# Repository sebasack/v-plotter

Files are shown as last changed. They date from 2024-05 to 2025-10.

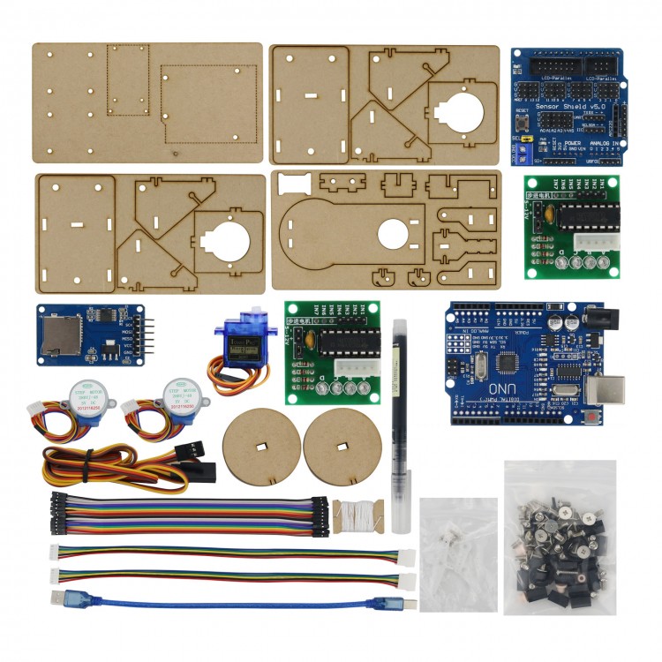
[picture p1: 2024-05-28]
hardware/mdf/1699426697-12-750x750.jpg

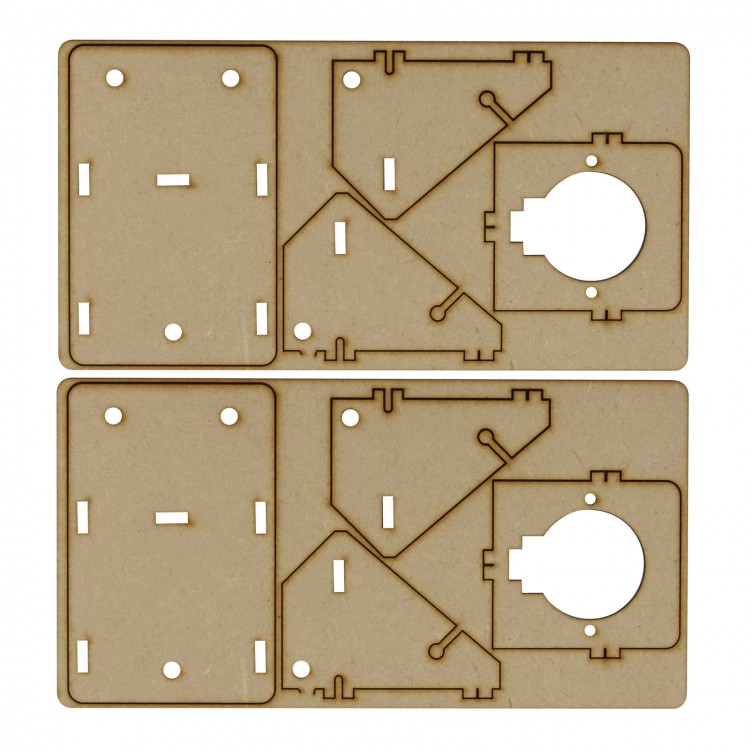
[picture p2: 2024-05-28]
hardware/mdf/1618448805-4-750x750.jpg

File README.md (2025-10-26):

# v-plotter

vertical plotter esp32 + wifi polargraph

      Como setear SSID y PASS de WIFI por primera vez:
      -----------------------------------------------

      1. Deshabilitar datos moviles del celular.
      2. Buscar la red llamada v-plotter y tratar de conecarse usando el pass '1234567890' .
      3. Entrar en la ip 192.168.4.1/config y configurar ssid y pass, presionar connect
      4. el AP v-plotter deberia desconectarse y deberia conectarse al wifi asignado.
      5. reiniciar el v-plotter
      6. en caso de falla recargar el firmware con la opcion 'Erase all flash before sketch upload' en Enabled, esto eliminara el ssid y pass guardados en la rom.

    Como plotear un svg:
    -------------------
       1. poner la gondola en posicion de dibujado (penDown)
       2. colocar la fibra en la gondola un milimetro por fuera de la estructura.
       3. poner la gondola en posicion de descanso (penLift)
       4. colocar el papel
       5. mover la gondola hasta su posicion de home, idealmente en el centro de la pizarra a 20 cms desde arriba.
       6. presionar el boton [input]->[set home]   para que la maquina sepa que ese es el punto de inicio.
       7. presionar [return to home] para asegurarse de que la gondola va as su home.
       8. borrar todo de la pantalla con [clear vector] y [clear image]
       9. presionar [load vector] y elegir la imagen, posicionarla en su lugar.
      10. presionar [move vector] para acomodarla y [resize vector] para acomodar su tamaÃ±o.
      11. presionar [select area] y elegir el area donde va a trabajar el plotter
      12. presionar [set frame to area]
      13. presionar [draw vector] para que genere el gcode
      14. presionar nuevamente [return to home] para que la gondola vuelva en su sitio inicial.
      15. activar la cola

    como convertir imagen a lineas y plotear:
    ----------------------------------------
       1. poner la gondola en posicion de dibujado (penDown)
       2. colocar la fibra en la gondola un milimetro por fuera de la estructura.
       3. poner la gondola en posicion de descanso (penLift)
       4. colocar el papel
       5. mover la gondola hasta su posicion de home, idealmente en el centro de la pizarra a 20 cms desde arriba.
       6. presionar el boton [input]->[set home]   para que la maquina sepa que ese es el punto de inicio.
       7. presionar [return to home] para asegurarse de que la gondola va as su home.
       8. borrar todo de la pantalla con [clear vector] y [clear image]
       9. presionar [load image from file] y elegir el archivo grafico
      10. poner en posicion con [move image]
      11. escalar con [resize image]
      12. presionar [select area] y elegir el area donde va a trabajar el plotter
      13. presionar [set frame to area]
      14. ir a [trace]
      15. presionar [capture]
      16. presionar [draw capture] para que genere el gcode
      17. ir a [input] para que muestre el path que seguira el plotter
      18. presionar nuevamente [return to home] para que la gondola vuelva en su sitio inicial.
      19. activar la cola

    Creaci�n de una imagen clasica (foto, dibujo, etc.)
    ---------------------------------------------------

       1. poner la gondola en posicion de dibujado (penDown)
       2. colocar la fibra en la gondola un milimetro por fuera de la estructura.
       3. poner la gondola en posicion de descanso (penLift)
       4. colocar el papel
       5. mover la gondola hasta su posicion de home, idealmente en el centro de la pizarra a 20 cms desde arriba.
       6. presionar el boton [input]->[set home]   para que la maquina sepa que ese es el punto de inicio.
       7. presionar [return to home] para asegurarse de que la gondola va as su home.
       8. borrar todo de la pantalla con [clear vector] y [clear image]
       9. presionar [load image from file] y elegir el archivo grafico
      10. poner en posicion con [move image]
      11. escalar con [resize image]
      12. presionar [select area] y elegir el area donde va a trabajar el plotter
      13. presionar [set frame to area]
      14. presionar [slect frame] para confirmar el �rea a dibujar.
      15. presionar [render pixels]

            Aparece una tabla con las diferentes opciones disponibles en cuanto a patrones, inicio y otras opciones:

            Deber�s elegir desde que punto comenzara el dibujo:
                  parte superior derecha
                  abajo a la derecha
                  abajo a la izquierda
                  arriba a la izquierda

            Hay 6 matrices de renderizado disponibles y deber�s elegir una para dibujar:
                  onda cuadrada de frecuencia variable
                  onda cuadrada de tama�o variable
                  onda cuadrada salida
                  garabatear
                  espirales
                  Diente de sierra

      16. presionar el bot�n [generate commands] para generar los comandos gcode.
      17. presionar nuevamente [return to home] para que la gondola vuelva en su sitio inicial.
      18. activar la cola

    Plotear archivo gcode guardado en SD:
    ------------------------------------
       1. poner la gondola en posicion de dibujado (penDown)
       2. colocar la fibra en la gondola un milimetro por fuera de la estructura.
       3. poner la gondola en posicion de descanso (penLift)
       4. colocar el papel
       5. mover la gondola hasta su posicion de home, idealmente en el centro de la pizarra a 20 cms desde arriba.
       6. presionar el boton [input]->[set home]   para que la maquina sepa que ese es el punto de inicio.
       7. presionar [return to home] para asegurarse de que la gondola va as su home.
       8. Crear el archivo gcode y guardarlo en el root de la SD con el nombre 'AUTORUN.TXT'
       9. reiniciar el sistema.

    Aclaraciones:
    ------------
      * aumentar el [setup]->[step multiplier]  le da mas resolucion a la impresion.
      * si se baja la resolucion parece escrito a mano.
      * Para imprimir texto pequeÃ±o primero pasarlo a hershey text usando inkscape, ir a 'Extensions' > 'Text' > 'Hershey Text'
        (fuente: https://support.shapertools.com/hc/en-us/articles/360055222354-Create-a-single-line-text-with-Inkscape)

    Instalar vpype para convertir imagenes a svg:
    --------------------------------------------

      * instalar con
            pipx install "vpype[all]"

      * instalar plugins
            pipx inject vpype vpype-vectrace
            pipx inject vpype deduplicate
            pipx inject vpype vpype-pixelart
            pipx inject vpype 'git+https://github.com/serycjon/vpype-flow-imager.git#egg=vpype-flow-imager[all]'
            pipx install vpype-ttf --include-deps
            pipx inject vpype vpype-occult
            pipx inject vpype hatched
            pipx inject vpype vpype-perspective
            pipx inject vpype vpype-gcode

      * desinstalarlo con
            pipx uninstall vpype

      * para entrar en la version dockerizada de vpype:
            docker exec -it vpype bash

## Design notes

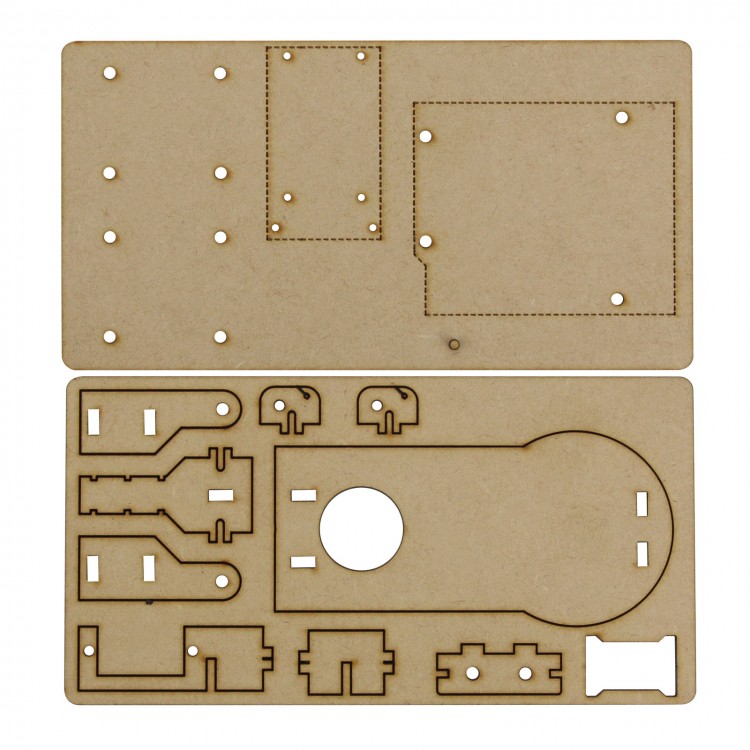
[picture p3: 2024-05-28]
hardware/mdf/1618448807-5-750x750.jpg

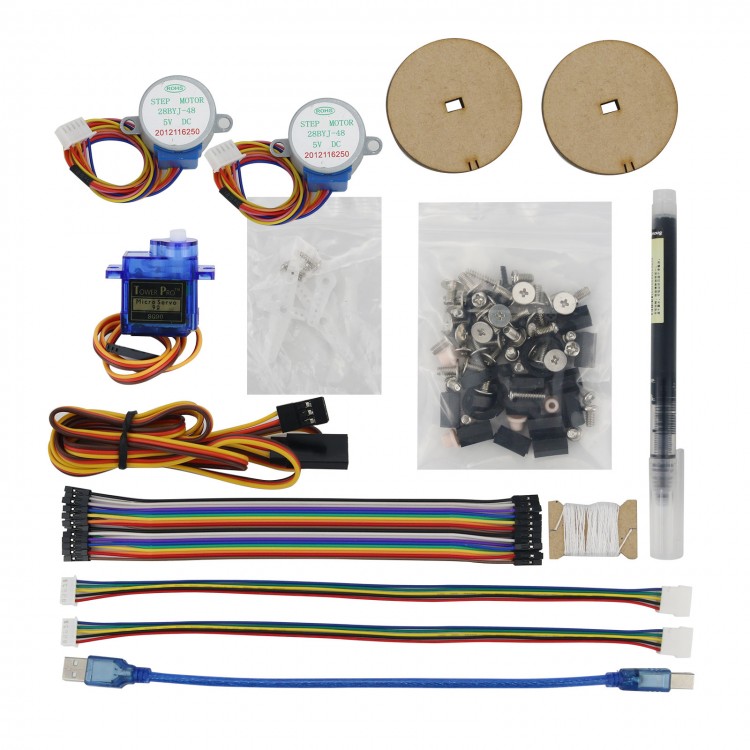
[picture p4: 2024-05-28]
hardware/mdf/1618448812-9-750x750.jpg

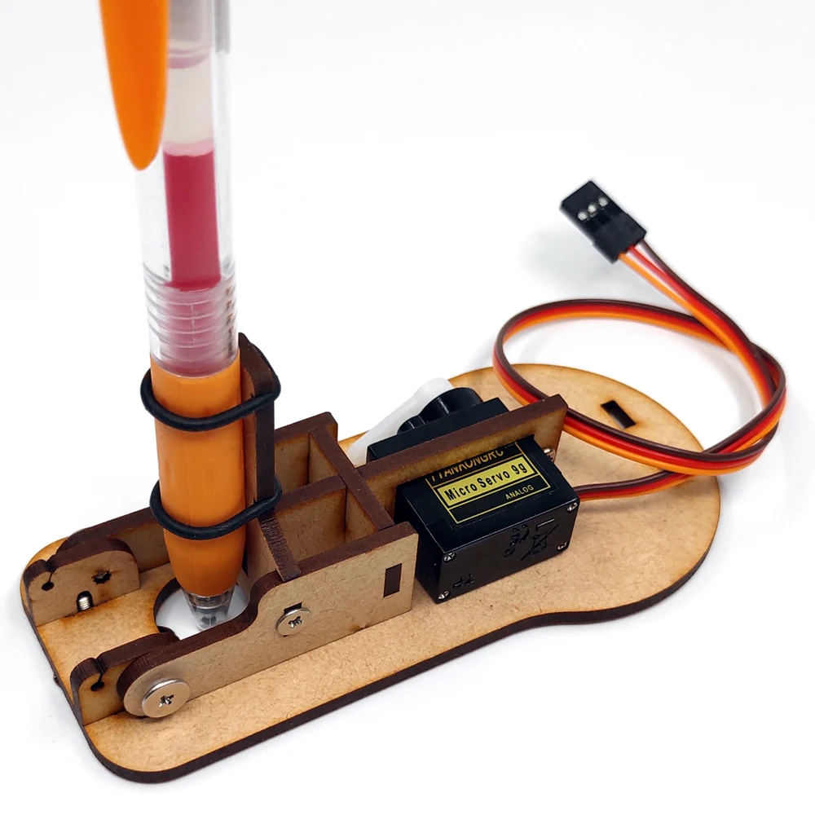
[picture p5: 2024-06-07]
hardware/mdf/H9e8e9794f45f4d0299c1774f670f7c20u.webp

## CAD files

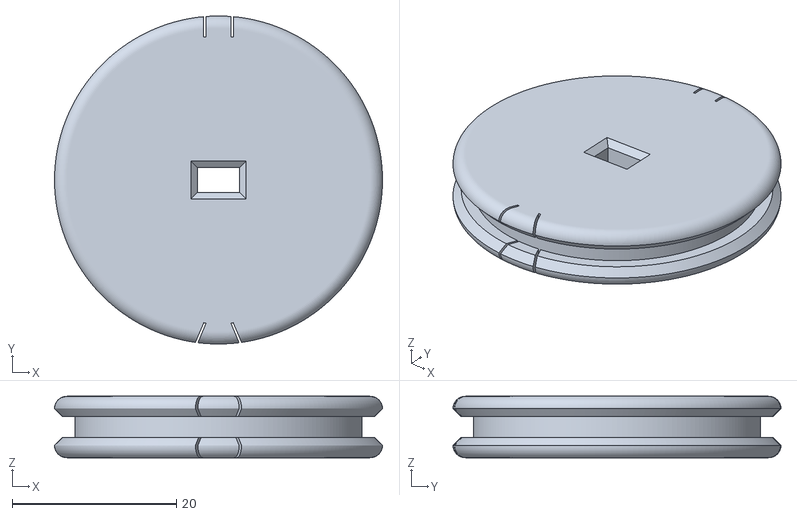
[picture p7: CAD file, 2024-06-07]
hardware/3d_printer/Spool.stl
40.0 x 40.0 x 7.50

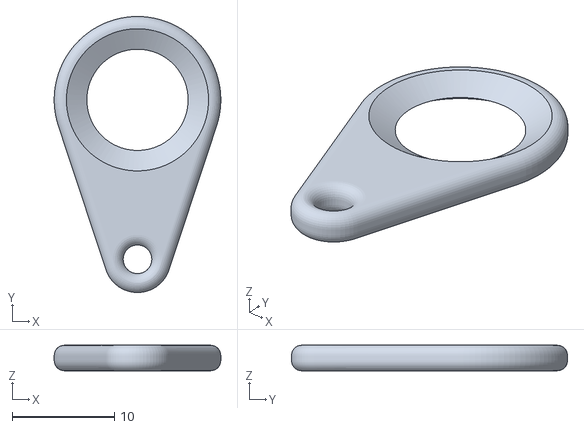
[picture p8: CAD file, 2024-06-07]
hardware/3d_printer/TwineRing.stl
16.3 x 27.0 x 2.50

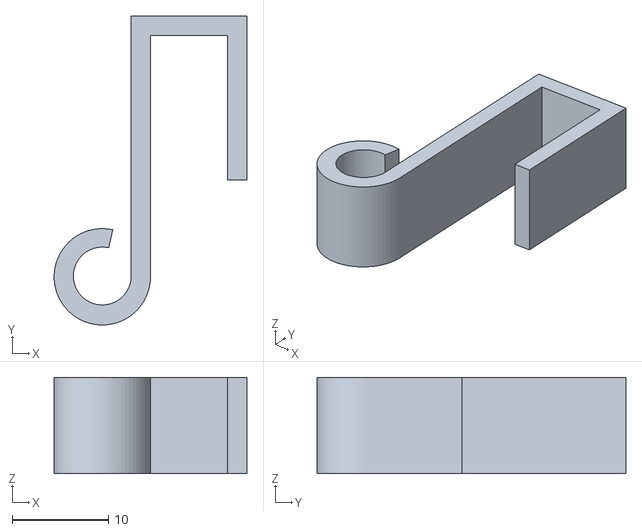
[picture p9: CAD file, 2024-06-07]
hardware/3d_printer/WireClamp.stl
20.0 x 32.1 x 10.0

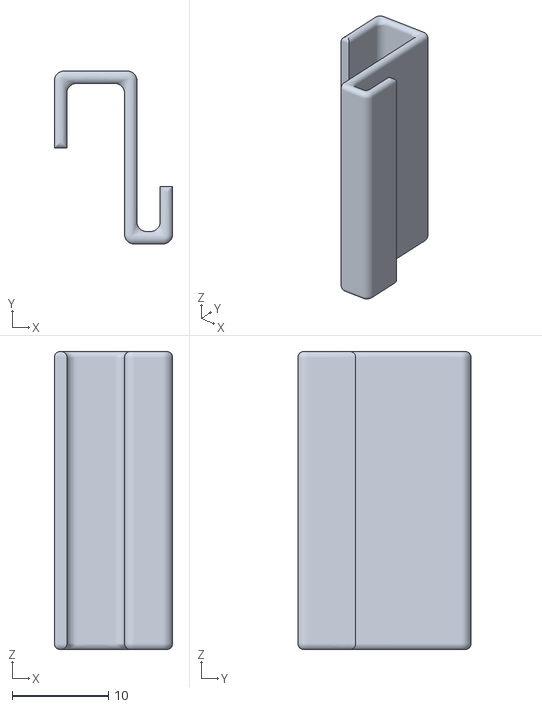
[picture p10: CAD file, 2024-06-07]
hardware/3d_printer/Hook.stl
12.3 x 18.0 x 31.0

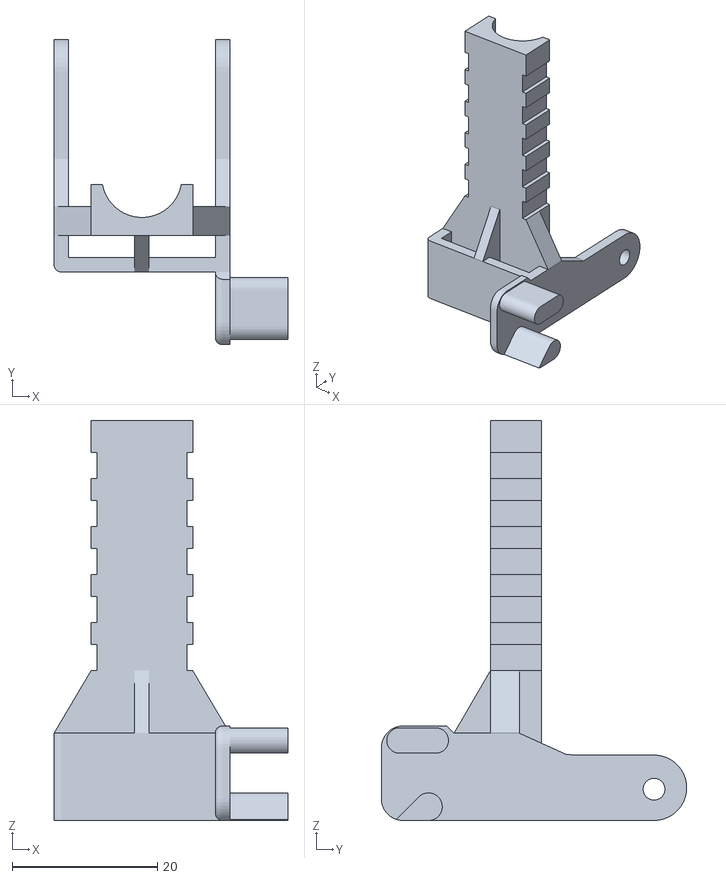
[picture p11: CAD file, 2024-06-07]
hardware/3d_printer/Lever.stl
32.2 x 42.0 x 55.0

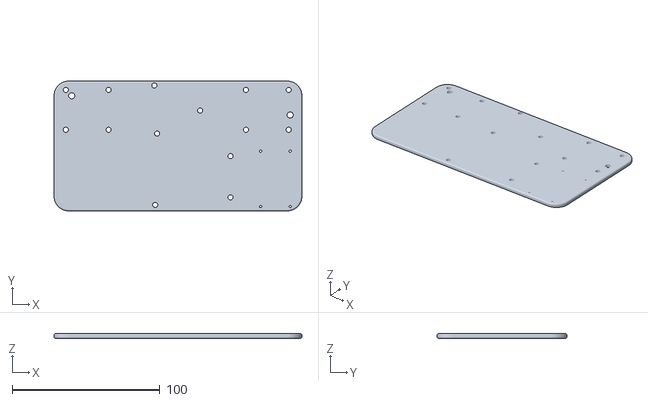
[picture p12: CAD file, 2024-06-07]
hardware/3d_printer/BasePlate Uno.stl
168.0 x 88.0 x 3.20

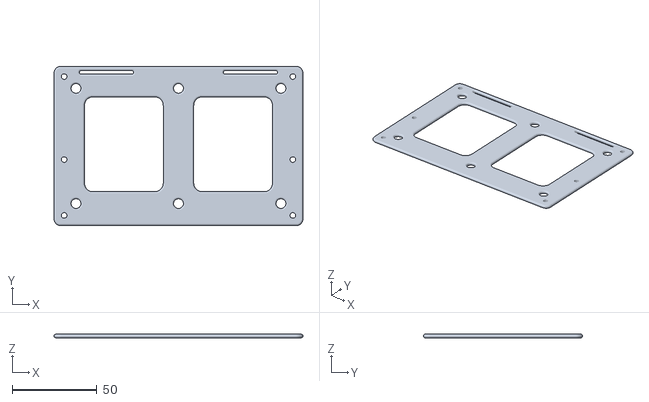
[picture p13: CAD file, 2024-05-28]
hardware/3d_printer/BasePlate PCB.stl
147.0 x 94.0 x 2.20

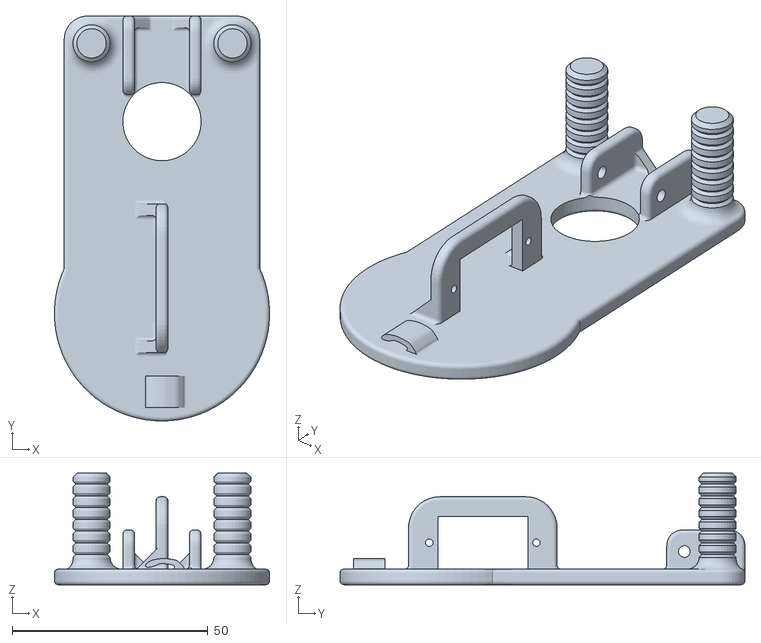
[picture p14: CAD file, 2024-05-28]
hardware/3d_printer/Sledge.stl
55.0 x 103.5 x 28.5

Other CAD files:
hardware/3d_printer/BasePlate.f3d
hardware/3d_printer/Sledge.f3d
hardware/3d_printer/Spool.f3d
hardware/3d_printer/StepperStand.f3d
hardware/3d_printer/WireClamp.f3d

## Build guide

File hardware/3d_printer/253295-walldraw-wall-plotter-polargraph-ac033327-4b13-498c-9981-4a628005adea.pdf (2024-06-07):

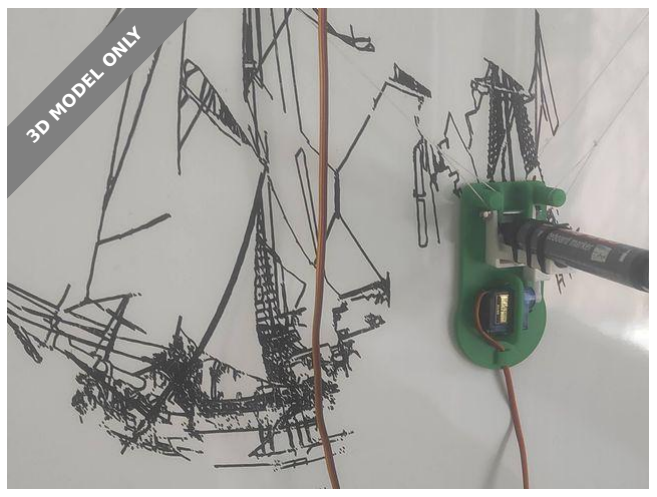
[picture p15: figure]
3D MODEL ONLY

## Summary

The Walldrawer project is a funny maker project for everyone.

Gadgets (https://www.printables.com/model?categoryId=21) > Other Gadgets (https://www.printables.com/model?categoryId=43)

Tags: arduino | esp32 | robotics | battery | electronics
fusion360 | office | pcb | programming | robotic
steppermotor | uln2003 | uno

The Walldrawer project is a usual maker project which is suitable for old and young.
There is so much fun in watching it working on giant sheets, walls or whiteboards.

I modified usual constructions, now everybody can build one on a 3D printer with an Arduino UNO
or, for the more engaged Makers, a selfmade PCB with ESP32.

My solution is below 30 bucks, beside some parts you may find around.

I published the full project in German language on GitHub: https://github.com/Pontifex42/Walldraw

Pontifex Maximus (https://www.printables.com/social/299558/about)

## Walldraw / Wall

## plotter / Polargraph

VIEW IN BROWSER (https://www.printables.com/model/253295-walldraw-wall-plotter-polargraph)

updated 6. 8. 2022 | published 6. 8. 2022

## Model files

There you find all files, code, instructions, part list photos, videos and all you need.
If requested, I'll translate everything to english.

spool.f3d

stepperstand.f3d

sledge.f3d

baseplate.f3d

wireclamp.f3d

sledge.stl

lever.stl

spool.stl

twinering.stl

## Other files

## License

This work is licensed under a
Creative Commons (4.0 International License)

Attribution-ShareAlike (http://creativecommons.org/licenses/by-sa/4.0/)

✖ | Sharing without ATTRIBUTION
✔ | Remix Culture allowed

stepperstand.stl

baseplate-pcb.stl

baseplate-uno.stl

wireclamp.stl

hook.stl

wandplotter.pdf

✔ | Commercial Use
✔ | Free Cultural Works
✔ | Meets Open Definition

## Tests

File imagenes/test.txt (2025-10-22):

C14,END
C01,15665,15665,END
C14,END
C17,16957,15583,2,END
C13,END
C17,20543,19423,2,END
C14,END
C17,19768,18039,2,END
C13,END
C17,19849,18105,2,END
C17,20055,18163,2,END
C17,20275,18114,2,END
C17,20374,18051,2,END
C17,20456,17968,2,END
C17,20555,17760,2,END
C17,20548,17541,2,END
C17,20505,17444,2,END
C17,20350,17306,2,END
C17,20248,17275,2,END
C17,20138,17272,2,END
C17,19921,17350,2,END
C17,19751,17520,2,END
C17,19674,17738,2,END
C17,19709,17950,2,END
C17,19766,18036,2,END
C14,END
C17,19827,16183,2,END
C13,END
C17,16515,19451,2,END
C14,END
C17,17670,18484,2,END
C13,END
C17,17657,18380,2,END
C17,17699,18270,2,END
C17,17785,18181,2,END
C17,17894,18133,2,END
C17,18000,18141,2,END
C17,18076,18200,2,END
C17,18105,18297,2,END
C17,18081,18408,2,END
C17,18008,18506,2,END
C17,17904,18567,2,END
C17,17794,18578,2,END
C17,17705,18534,2,END
C14,END
C17,18794,20058,2,END
C13,END
C17,19155,19246,2,END
C17,18624,19381,2,END
C17,18758,20137,2,END
C14,END
C17,18791,16124,2,END
C13,END
C17,17686,15547,2,END
C14,END
C17,16646,16331,2,END
C13,END
C17,17755,16525,2,END
C17,18905,15452,2,END
C17,18392,16780,2,END
C17,18445,16837,2,END
C17,19457,17258,2,END
C17,18002,17707,2,END
C17,17532,19158,2,END
C17,17076,18089,2,END
C17,15735,18598,2,END
C17,16825,17455,2,END
C17,16646,16337,2,END
C14,END
C17,16025,17493,2,END
C13,END
C17,16213,17300,2,END
C17,16335,17415,2,END
C17,16149,17607,2,END
C17,16086,17550,2,END
C14,END
C17,15927,17584,2,END
C13,END
C17,16115,17754,2,END
C17,16484,17383,2,END
C17,16248,17150,2,END
C17,15872,17534,2,END
C14,END
C17,15767,17620,2,END
C13,END
C17,16081,17902,2,END
C17,16633,17353,2,END
C17,16285,17000,2,END
C17,15719,17576,2,END
C14,END
C17,15612,17664,2,END
C13,END
C17,16055,18057,2,END
C17,16789,17317,2,END
C17,16322,16846,2,END
C17,15563,17620,2,END
C14,END
C17,14722,17955,2,END
C13,END
C17,18689,21329,2,END
C17,18769,21332,2,END
C17,21747,18410,2,END
C17,21766,18332,2,END
C17,18467,14260,2,END
C17,18418,14201,2,END
C17,14671,17913,2,END
C14,END
C17,14417,18036,2,END
C13,END
C17,18707,21619,2,END
C17,18789,21651,2,END
C17,22061,18441,2,END
C17,22098,18365,2,END
C17,18545,13886,2,END
C17,14380,18006,2,END
C14,END
C01,15665,15665,END

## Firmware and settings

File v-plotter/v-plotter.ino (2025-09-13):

/**
*  Polargraph Server for ESP32 based microcontroller boards.
*  Written by Sandy Noble
*  Released under GNU License version 3.
*  http://www.polargraph.co.uk
*  https://github.com/euphy/polargraph_server_polarshield_esp32
*  https://github.com/euphy/polargraph/wiki
*  https://github.com/obstruse/PGNH/tree/main



This version is for the Polarshield 3, which aggregates:

  * ESP32 DOIT-DEVKIT V1 
  * 2x UNL2003 stepper drivers   
  * SD card reader     

**/

char fileName[] = __FILE__;
char temp[1000];



#include "wifiTask.h"
#include "httpTask.h"
#include "httpWifiTask.h"
// #include "commsTask.h"

#include <SD.h>
#include "FS.h"
#include "SPIFFS.h"
#include <SPI.h>
// #include <TFT_eSPI.h> // Hardware-specific library

#include <AccelStepper.h>
#include <MultiStepper.h>
#include <ESP32Servo.h>

#include <Preferences.h>



/*
Avoid global variables whenever possible...
*/

/* Definition of a function that can be attached to a Button Specification
and will get executed when the button is pushed..
*/
// typedef int (*button_Action) (int buttonId);


// 2D coordinates struct
typedef struct
{
  long x;
  long y;
} Coord2D;

typedef struct
{
  Coord2D pos;
  Coord2D size;
} Rectangle;


/*  ===========================================================
         CONFIGURATION!!
    =========================================================== */

/*  ===========================================================
         Define what kind of driver breakout you're using.
         (By commenting out the one's you _haven't_ got.)
    =========================================================== */
#ifndef MOTHERBOARD
// #define MOTHERBOARD NODEMCU32S
// #define MOTHERBOARD POLARSHIELD
// #define MOTHERBOARD RAMPS14
// #define MOTHERBOARD TFTSHIELD

#define MOTHERBOARD ESP32_UNL2003

#endif

// #define POLARSHIELD 1
// #define RAMPS14 2
// #define TFTSHIELD 3
// #define NODEMCU32S 4
#define ESP32_UNL2003 5

/*  ===========================================================
    Control whether to look for touch input or update LCD
    Comment this out if you DON'T have an LCD connected
=========================================================== */
// #define USE_LCD

/*  ===========================================================
    Some debugging flags
=========================================================== */

// #define DEBUG_COMMS
// #define DEBUG_COMMS_BUFF
//  #define DEBUG_PENLIFT
//  #define DEBUG_STEPRATE

boolean debugComms = false;

// Set REPEAT_CAL to true instead of false to run calibration
// again, otherwise it will only be done once.
// Repeat calibration if you change the screen rotation.
#define REPEAT_CAL false

/*  ===========================================================
    These variables are common to all polargraph server builds
=========================================================== */

const String FIRMWARE_VERSION_NO = "2.3.0";


#if MOTHERBOARD == RAMPS14
const String MB_NAME = "RAMPS14";
#elif MOTHERBOARD == NODEMCU32S
const String MB_NAME = "NODEMCU32S";
#elif MOTHERBOARD == POLARSHIELD
const String MB_NAME = "POLARSHIELD";
#elif MOTHERBOARD == TFTSHIELD
const String MB_NAME = "TFTSHIELD";
#elif MOTHERBOARD == ESP32_UNL2003
const String MB_NAME = "ESP32_UNL2003";
#endif

/*  ===========================================================
    Preferences is the way to store non-volatile values in ESP32.
=========================================================== */

Preferences preferences;

// Pen raising servo , CAMBIAR DESDE POLARGRAPH!!
Servo penHeight;
const int DEFAULT_DOWN_POSITION =90;//90
const int DEFAULT_UP_POSITION = 123;//180
static int upPosition = DEFAULT_UP_POSITION;
static int downPosition = DEFAULT_DOWN_POSITION;
static int penLiftSpeed = 3; // ms between steps of moving motor
#if MOTHERBOARD == RAMPS14
#define PEN_HEIGHT_SERVO_PIN 4
#elif MOTHERBOARD == POLARSHIELD
#define PEN_HEIGHT_SERVO_PIN 9
#elif MOTHERBOARD == NODEMCU32S
#define PEN_HEIGHT_SERVO_PIN 22
#elif MOTHERBOARD == ESP32_UNL2003
#define PEN_HEIGHT_SERVO_PIN 15
#endif
boolean isPenUp = false;

// working machine specification
const long DEFAULT_MACHINE_WIDTH = 882;
const long DEFAULT_MACHINE_HEIGHT = 1100;
const float DEFAULT_MM_PER_REV = 125.66;
const int DEFAULT_STEPS_PER_REV = 4076;
const int DEFAULT_STEP_MULTIPLIER = 8; // mas chico tiene menos resolucion

static int motorStepsPerRev = DEFAULT_STEPS_PER_REV;
static float mmPerRev = DEFAULT_MM_PER_REV;
static int stepMultiplier = DEFAULT_STEP_MULTIPLIER;

static Coord2D machineSizeMm = {DEFAULT_MACHINE_WIDTH, DEFAULT_MACHINE_HEIGHT};

 // float startLength = ((float) startLengthMM / (float) mmPerRev) * (float) motorStepsPerRev;
 //                   =         481   /   125.66          * 4076
 //                   =                   15704.828
static long startLengthStepsA = 125312;// 15664 * 8
static long startLengthStepsB = 125312;// 15664 * 8

const float DEFAULT_MAX_SPEED = 1000.0;
const float DEFAULT_ACCELERATION = 400.0;
float currentMaxSpeed = DEFAULT_MAX_SPEED;
static float currentAcceleration = DEFAULT_ACCELERATION;
volatile static boolean usingAcceleration = true;

float mmPerStep = mmPerRev / (stepMultiplier * motorStepsPerRev);
float stepsPerMm = (stepMultiplier * motorStepsPerRev) / mmPerRev;

static Coord2D machineSizeSteps = {(long)((float)machineSizeMm.x * stepsPerMm), (long)((float)machineSizeMm.y *stepsPerMm)};
static long maxLength = 0;

const float DEFAULT_PEN_WIDTH = 0.5f;//0.f8
static float penWidth = DEFAULT_PEN_WIDTH; // line width in mm

/*==========================================================================
    COMMUNICATION PROTOCOL, how to chat
  ========================================================================*/

// max length of incoming command
const int INLENGTH = 90;
const char INTERMINATOR = 10;
const char SEMICOLON = 59;

// static char currentCommand[INLENGTH+1];
char currentCommand[INLENGTH + 1];
char currentCommandRaw[INLENGTH + 1];

static char inCmd[10];
static char inParam1[20];
static char inParam2[20];
static char inParam3[20];
static char inParam4[20];
static byte inNoOfParams = 0;
boolean paramsExtracted = false;
// boolean usingCrc = false;

boolean reportingPosition = true;
// boolean requestResend = false;
// boolean checkingForReceivedCommand = false;

#define OUT_CMD_SYNC_STR "SYNC,"

char MSG_ERROR_STR[] = "MSG,E,";
char MSG_INFO_STR[] = "MSG,I,";
char MSG_DEBUG_STR[] = "MSG,D,";
char MSG_COMPLETE_STR[] = "MSG,C:";

// period between status rebroadcasts
// unsigned long comms_rebroadcastStatusInterval =4000;// estaba en 4000
// Chrono broadcastStatusChrono;

/*==========================================================================
    MOTOR interfaces
  ========================================================================*/

extern AccelStepper motorA;
extern AccelStepper motorB;

volatile boolean currentlyRunning = true;
volatile boolean backgroundRunning = false;

volatile long lastOperationTime = 0L;
static long motorIdleTimeBeforePowerDown = 30000L; // 30000=30 seg
static boolean automaticPowerDown = true;
volatile long lastInteractionTime = 0L;

// Pixel drawing
static boolean pixelDebug = true;
static boolean lastWaveWasTop = true;

//  Drawing direction
const static byte DIR_NE = 1;
const static byte DIR_SE = 2;
const static byte DIR_SW = 3;
const static byte DIR_NW = 4;

const static byte DIR_N = 5;
const static byte DIR_E = 6;
const static byte DIR_S = 7;
const static byte DIR_W = 8;

static int globalDrawDirection = DIR_NW;

const static byte DIR_MODE_AUTO = 1;
const static byte DIR_MODE_PRESET = 2;
const static byte DIR_MODE_RANDOM = 3;
static int globalDrawDirectionMode = DIR_MODE_AUTO;

static const byte ALONG_A_AXIS = 0;
static const byte ALONG_B_AXIS = 1;
static const byte SQUARE_SHAPE = 0;
static const byte SAW_SHAPE = 1;

// Command names
const static char COMMA[] = ",";
const static char CMD_END[] = ",END";
const static String CMD_CHANGELENGTH = "C01";
const static String CMD_SETPENWIDTH = "C02";
const static String CMD_DRAWPIXEL = "C05";
const static String CMD_DRAWSCRIBBLEPIXEL = "C06";
const static String CMD_CHANGEDRAWINGDIRECTION = "C08";
const static String CMD_SETPOSITION = "C09";
const static String CMD_TESTPATTERN = "C10";
const static String CMD_TESTPENWIDTHSQUARE = "C11";
const static String CMD_PENDOWN = "C13";
const static String CMD_PENUP = "C14";
const static String CMD_CHANGELENGTHDIRECT = "C17";
const static String CMD_SETMACHINESIZE = "C24";
const static String CMD_SETMACHINENAME = "C25";
const static String CMD_GETMACHINEDETAILS = "C26";
const static String CMD_RESETEEPROM = "C27";
const static String CMD_SETMACHINEMMPERREV = "C29";
const static String CMD_SETMACHINESTEPSPERREV = "C30";
const static String CMD_SETMOTORSPEED = "C31";
const static String CMD_SETMOTORACCEL = "C32";
const static String CMD_SETMACHINESTEPMULTIPLIER = "C37";
const static String CMD_SETPENLIFTRANGE = "C45";
const static String CMD_PIXELDIAGNOSTIC = "C46";
const static String CMD_SET_DEBUGCOMMS = "C47";

// Instrumentation about running background motor tasks
volatile DRAM_ATTR long runCounter = 0L;
volatile DRAM_ATTR long lastPeriodStartTime = 0L;
volatile DRAM_ATTR long sampleBuffer[3] = {0L, 0L, 0L};
volatile DRAM_ATTR int sampleBufferSlot = 0;
volatile DRAM_ATTR long totalTriggers = 0L;
volatile DRAM_ATTR long totalSamplePeriods = 0L;
volatile DRAM_ATTR long steppedCounter = 0L;
volatile DRAM_ATTR long steppedBuffer[3] = {0L, 0L, 0L};
volatile DRAM_ATTR boolean aStepped = false;
volatile DRAM_ATTR boolean bStepped = false;

SemaphoreHandle_t xMutex;

// Ticker commsRunner;

/*===========================================================
    These variables are for the polarshield
=========================================================== */

const static String CMD_TESTPENWIDTHSCRIBBLE = "C12";
const static String CMD_DRAWSAWPIXEL = "C15,";
const static String CMD_DRAWCIRCLEPIXEL = "C16";
const static String CMD_SET_ROVE_AREA = "C21";
const static String CMD_DRAWDIRECTIONTEST = "C28";
const static String CMD_MODE_STORE_COMMANDS = "C33";
const static String CMD_MODE_EXEC_FROM_STORE = "C34";
const static String CMD_MODE_LIVE = "C35";
const static String CMD_RANDOM_DRAW = "C36";
const static String CMD_START_TEXT = "C38";
const static String CMD_DRAW_SPRITE = "C39";
const static String CMD_CHANGELENGTH_RELATIVE = "C40";
const static String CMD_SWIRLING = "C41";
const static String CMD_DRAW_RANDOM_SPRITE = "C42";
const static String CMD_DRAW_NORWEGIAN = "C43";
const static String CMD_DRAW_NORWEGIAN_OUTLINE = "C44";
const static String CMD_AUTO_CALIBRATE = "C48";

/*  End stop pin definitions  */
// there are no endstop switches, so this and the calibrate can be removed
const int ENDSTOP_MOTORA_PIN = 34;
const int ENDSTOP_MOTORB_PIN = 35;

long limitStepsMotorA = 0;
long limitStepsMotorB = 0;


// size and location of rove area
Rectangle roveAreaMm = {200, 120, 210, 297};
Rectangle roveAreaSteps = {
    (long)((float)roveAreaMm.pos.x * stepsPerMm), (long)((float)roveAreaMm.pos.y *stepsPerMm),
    (long)((float)roveAreaMm.size.x *stepsPerMm), (long)((float)roveAreaMm.size.y *stepsPerMm)};

boolean swirling = false;
String spritePrefix = "";
int textRowSize = 200;
int textCharSize = 180;

boolean useRoveArea = false;

int commandNo = 0;
int errorInjection = 0;

boolean storeCommands = false;
boolean drawFromStore = false;
String commandFilename = "";

// sd card stuff
const int sdChipSelectPin = 05;
//boolean sdCardInit = false;

// set up variables using the SD utility library functions:
File root;
boolean cardPresent = false;
boolean cardInit = false;
boolean echoingStoredCommands = false;

// the file itself
File pbmFile;

// information we extract about the bitmap file
long pbmWidth, pbmHeight;
float pbmScaling = 1.0;
int pbmDepth, pbmImageoffset;
long pbmFileLength = 0;
float pbmAspectRatio = 1.0;

volatile int speedChangeIncrement = 100;
volatile int accelChangeIncrement = 100;
volatile float penWidthIncrement = 0.05;
volatile int moveIncrement = 400;

// buttons_actions.ino, impl_ps.ino, sd.ino
boolean currentlyDrawingFromFile = false;
String currentlyDrawingFilename = "";

// calibrate.ino, impl_ps.ino
boolean powerIsOn = false;
boolean isCalibrated = false;
boolean canCalibrate = false;

// Colour scheme
// As seen on http://www.barth-dev.de/online/rgb565-color-picker/
// uint16_t getAsRgb565(uint8_t red, uint8_t green, uint8_t blue){
//  return (((red & 0b11111000)<<8) + ((green & 0b11111100)<<3)+(blue>>3));
//}

/*-----------------------------------------------------------------*/
/*-----------------------------------------------------------------*/
void setup(){
  Serial.begin(115200); // set up Serial library at 57600 bps
  Serial.println(F("\nPOLARGRAPH ON!"));
  Serial.print(F("v"));
  Serial.println(FIRMWARE_VERSION_NO);
  Serial.print(F("Hardware: "));
  Serial.println(MB_NAME);



  Serial.print(F("Servo pin: "));
  Serial.println(PEN_HEIGHT_SERVO_PIN);

  /*-----------------------------------------------------------------*/
  configuration_motorSetup();

  // Load configuration
  preferences.begin("polargraphsd", false);
  eeprom_loadMachineSpecFromEeprom();
  configuration_setup();

  /*-----------------------------------------------------------------*/
  Serial.println("create task: wifi");
  wifiTaskCreate();

  Serial.println("create task: http");
  httpTaskCreate();
  httpWifiTaskCreate();

  /*-----------------------------------------------------------------*/
  Serial.println("create task: commsRead"); // read command
  commsReadTaskCreate();

  Serial.println("create task: commsCommand"); // execute command
  commsCommandTaskCreate();

  Serial.println("create task: releaseMotors"); // chequea si tiene que desenergizar motores
  implReleaseMotorsCreate();

//  Serial.println("create task: externalControl"); // tarea que maneja el control externo de los motores
  //externalControlCreate();


//  Serial.println("create task: remoteDebug"); // actualiza debug
//  Serial.remoteDebugCreate();

  //*-----------------------------------------------------------------*/
  // set the pen lift, raise it to begin.
  pinMode(PEN_HEIGHT_SERVO_PIN, OUTPUT);
  delay(200);
  penlift_penUp();

  /* set endstop motors pins */
  pinMode(ENDSTOP_MOTORA_PIN, INPUT_PULLUP);
  pinMode(ENDSTOP_MOTORB_PIN, INPUT_PULLUP);

  sd_autorunSD();
}

/*-----------------------------------------------------------------*/
/*-----------------------------------------------------------------*/
void loop(){
  // vTaskDelete(NULL);
  vTaskDelay(portMAX_DELAY);

  
}

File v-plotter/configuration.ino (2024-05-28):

/**
*  Polargraph Server for ESP32 based microcontroller boards.
*  Written by Sandy Noble
*  Released under GNU License version 3.
*  http://www.polargraph.co.uk
*  https://github.com/euphy/polargraph_server_polarshield_esp32

Configuration.

This is one of the core files for the polargraph server program.
It sets up the motor objects (AccelSteppers), and has default
values for the motor, sprocket and microstepping combinations used
by polargraphs so far.

*/

// =================================================================
// Polarshield motor driver board
// This uses stepstick-format stepper drivers on arduino pins 3 to 8.



#if MOTHERBOARD == POLARSHIELD
  #define MOTOR_A_ENABLE_PIN 3
  #define MOTOR_A_STEP_PIN 4
  #define MOTOR_A_DIR_PIN 5

  #define MOTOR_B_ENABLE_PIN 6
  #define MOTOR_B_STEP_PIN 7
  #define MOTOR_B_DIR_PIN 8

  #define MOTOR_C_ENABLE_PIN 30
  #define MOTOR_C_STEP_PIN 31  
  #define MOTOR_C_DIR_PIN 32
  AccelStepper motorA(1, MOTOR_A_STEP_PIN, MOTOR_A_DIR_PIN);
  AccelStepper motorB(1, MOTOR_B_STEP_PIN, MOTOR_B_DIR_PIN);

#elif MOTHERBOARD == RAMPS14

  // Uses E1 driver on RAMPS
  #define MOTOR_A_ENABLE_PIN 30
  #define MOTOR_A_STEP_PIN 36
  #define MOTOR_A_DIR_PIN 34

  // Uses Y motor driver on RAMPS
  #define MOTOR_B_ENABLE_PIN 56
  #define MOTOR_B_STEP_PIN 60
  #define MOTOR_B_DIR_PIN 61
  AccelStepper motorA(1, MOTOR_A_STEP_PIN, MOTOR_A_DIR_PIN);
  AccelStepper motorB(1, MOTOR_B_STEP_PIN, MOTOR_B_DIR_PIN);

#elif MOTHERBOARD == TFTSHIELD

  // Uses E1 driver on RAMPS
  #define MOTOR_A_ENABLE_PIN 21
  #define MOTOR_A_STEP_PIN 20
  #define MOTOR_A_DIR_PIN 19

  // Uses Y motor driver on RAMPS
  #define MOTOR_B_ENABLE_PIN 18
  #define MOTOR_B_STEP_PIN 17
  #define MOTOR_B_DIR_PIN 16
  AccelStepper motorA(1, MOTOR_A_STEP_PIN, MOTOR_A_DIR_PIN);
  AccelStepper motorB(1, MOTOR_B_STEP_PIN, MOTOR_B_DIR_PIN);

#elif MOTHERBOARD == NODEMCU32S

  #define MOTOR_A_ENABLE_PIN 27
  #define MOTOR_A_STEP_PIN 14
  #define MOTOR_A_DIR_PIN 12

  #define MOTOR_B_ENABLE_PIN 13
  #define MOTOR_B_STEP_PIN 4
  #define MOTOR_B_DIR_PIN 15
  AccelStepper motorA(1, MOTOR_A_STEP_PIN, MOTOR_A_DIR_PIN);
  AccelStepper motorB(1, MOTOR_B_STEP_PIN, MOTOR_B_DIR_PIN);

#elif MOTHERBOARD == ESP32_UNL2003
    // Contributed by @j0nson
    // Initialize ULN2003 stepper driver
    // first number is type of stepper motor, 4 for a normal 4 wire step motor, 8 for a halfstepped normal 4 wire motor
    //Connection Directions
    // MotorA
    //ULN2003  Arduino  AcceStepper Init
    //IN1      2        2
    //IN2      3        4
    //IN3      4        3
    //IN4      5        5
    // MotorB
    //ULN2003  Arduino  AcceStepper Init
    //IN1      6        6
    //IN2      7        8
    //IN3      8        7
    //IN4      9        9
    
    //for a 28YBJ-48 Stepper, change these parameters above
    //Step angle (8-step) 5.625deg, 64 steps per rev
    //Step angle (4-step) 11.25deg, 32 steps per rev
    //gear reduction ratio 1/63.68395
    
    // motorStepsPerRev = 32 * 63.68395 = 2038; //for 4 step sequence
    // motorStepsPerRev = 64 * 63.68395 = 4076; //for 8 step sequence
    
    //motorStepsPerRev = 4076;
    //mmPerRev = 63;
    
    //DEFAULT_STEPS_PER_REV = 4076;
    //DEFAULT_MM_PER_REV = 63;
    
       
  // AccelStepper motorA(8, 26,33,32,25);  //   
  // AccelStepper motorB(8, 13,14,27,12);  //   

// esta configuracion dibuja invertido de cabeza
 //   AccelStepper motorA(8, 25,32,33,26);  //inv
  //  AccelStepper motorB(8, 13,14,27,12);  
       
    AccelStepper motorA(8, 26,33,32,25);
    AccelStepper motorB(8, 12,27,14,13);  //inv
       
  //  AccelStepper motorA(8, 25,32,33,26);  //inv
  //  AccelStepper motorB(8, 12,27,14,13);  //inv

//INVIERTO A Y B

  //  AccelStepper motorB(8, 26,33,32,25);
  //  AccelStepper motorA(8, 13,14,27,12);  
       
  //  AccelStepper motorB(8, 25,32,33,26);  //inv
  //  AccelStepper motorA(8, 13,14,27,12);  
       
  //  AccelStepper motorB(8, 26,33,32,25);
  //  AccelStepper motorA(8, 12,27,14,13);  //inv
       
  //  AccelStepper motorB(8, 25,32,33,26);  //inv
  //  AccelStepper motorA(8, 12,27,14,13);  //inv

   



#endif




void configuration_motorSetup(){

#ifdef DEBUG
  Serial.print(F("A: En:"));
  Serial.print(MOTOR_A_ENABLE_PIN);
  Serial.print(F(", St:"));
  Serial.print(MOTOR_A_STEP_PIN);
  Serial.print(F(", Di:"));
  Serial.println(MOTOR_A_DIR_PIN);

  Serial.print(F("B: En:"));
  Serial.print(MOTOR_B_ENABLE_PIN);
  Serial.print(F(", St:"));
  Serial.print(MOTOR_B_STEP_PIN);
  Serial.print(F(", Di:"));
  Serial.println(MOTOR_B_DIR_PIN);
#endif
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

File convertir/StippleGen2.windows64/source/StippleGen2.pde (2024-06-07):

/**
 
 StippleGen_2_31
 
 SVG Stipple Generator, v. 2.31
 Copyright (C) 2013 by Windell H. Oskay, www.evilmadscientist.com
 
 Full Documentation: http://wiki.evilmadscience.com/StippleGen
 Blog post about the release: http://www.evilmadscientist.com/go/stipple2
 
 
 An implementation of Weighted Voronoi Stippling:
 http://mrl.nyu.edu/~ajsecord/stipples.html
 
 *******************************************************************************
 
 Change Log:
 
 
 v 2.3
 * Forked from 2.1.1
 * Fixed saving bug
 
 v 2.20
 * [Cancelled development branch.]
 
 v 2.1.1
 * Faster now, with number of stipples calculated at a time.
 
 v 2.1.0
 * Now compiling in Processing 2.0b6
 * selectInput() and selectOutput() calls modified for Processing 2.
 
 v 2.02
 * Force files to end in .svg
 * Fix bug that gave wrong size to stipple files saved white stipples on black background
 
 v 2.01:  
 * Improved handling of Save process, to prevent accidental "not saving" by users.
 
 v 2.0:  
 * Add tone reversal option (white on black / black on white)
 * Reduce vertical extent of GUI, to reduce likelihood of cropping on small screens
 * Speling corections 
 * Fixed a bug that caused unintended cropping of long, wide images
 * Reorganized GUI controls
 * Fail less disgracefully when a bad image type is selected.
 
 *******************************************************************************
 
 
 
 Program is based on the Toxic Libs Library ( http://toxiclibs.org/ )
 & example code:
 http://forum.processing.org/topic/toxiclib-voronoi-example-sketch
 
 
 Additional inspiration:
 Stipple Cam from Jim Bumgardner
 http://joyofprocessing.com/blog/2011/11/stipple-cam/
 
 and 
 
 MeshLibDemo.pde - Demo of Lee Byron's Mesh library, by 
 Marius Watz - http://workshop.evolutionzone.com/
 
 
 Requires ControlP5 library and Toxic Libs library:
 http://www.sojamo.de/libraries/controlP5/
 http://hg.postspectacular.com/toxiclibs/downloads
 
 
 */


/*  
 * 
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
 * http://creativecommons.org/licenses/LGPL/2.1/
 * 
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
 * You should have received a copy of the GNU Lesser General Public
 * License along with this library; if not, write to the Free Software
 * Foundation, Inc., 51 Franklin St, Fifth Floor, Boston, MA  02110-1301  USA
 */


// You need the controlP5 library from http://www.sojamo.de/libraries/controlP5/
import controlP5.*;    

//You need the Toxic Libs library: http://hg.postspectacular.com/toxiclibs/downloads

import toxi.geom.*;
import toxi.geom.mesh2d.*;
import toxi.util.datatypes.*;
import toxi.processing.*;

// helper class for rendering
ToxiclibsSupport gfx;

import javax.swing.UIManager; 
import javax.swing.JFileChooser; 




// Feel free to play with these three default settings:
int maxParticles = 2000;   // Max value is normally 10000.  Press 'x' key to allow 50000 stipples. (SLOW)
float MinDotSize = 1.75; //2;
float DotSizeFactor = 4;  //5;
float cutoff =  0;  // White cutoff value


int cellBuffer = 100;  //Scale each cell to fit in a cellBuffer-sized square window for computing the centroid.


// Display window and GUI area sizes:
int mainwidth; 
int mainheight;
int borderWidth;
int ctrlheight;
int TextColumnStart;



float lowBorderX;
float hiBorderX;
float lowBorderY;
float hiBorderY;



float MaxDotSize;
boolean ReInitiallizeArray; 
boolean pausemode;
boolean fileLoaded;
int SaveNow;
String savePath;
String[] FileOutput; 




String StatusDisplay = "Initializing, please wait. :)";
float millisLastFrame = 0;
float frameTime = 0;

String ErrorDisplay = "";
float ErrorTime;
Boolean ErrorDisp = false;


int Generation; 
int particleRouteLength;
int RouteStep; 

boolean showBG;
boolean showPath;
boolean showCells; 
boolean invertImg;
boolean TempShowCells;
boolean FileModeTSP;

int vorPointsAdded;
boolean VoronoiCalculated;

// Toxic libs library setup:
Voronoi voronoi; 
Polygon2D RegionList[];

PolygonClipper2D clip;  // polygon clipper

int cellsTotal, cellsCalculated, cellsCalculatedLast;


// ControlP5 GUI library variables setup
Textlabel  ProgName; 
Button  OrderOnOff, ImgOnOff, CellOnOff, InvertOnOff, PauseButton;
ControlP5 cp5; 


PImage img, imgload, imgblur; 

Vec2D[] particles;
int[] particleRoute;



void LoadImageAndScale() {

  int tempx = 0;
  int tempy = 0;

  img = createImage(mainwidth, mainheight, RGB);
  imgblur = createImage(mainwidth, mainheight, RGB);

  img.loadPixels();

  if (invertImg)
    for (int i = 0; i < img.pixels.length; i++) {
      img.pixels[i] = color(0);
    }
  else
    for (int i = 0; i < img.pixels.length; i++) {
      img.pixels[i] = color(255);
    }

  img.updatePixels();

  if ( fileLoaded == false) {
    // Load a demo image, at least until we have a "real" image to work with.

    imgload = loadImage("grace.jpg"); // Load demo image
    // Image source:  http://commons.wikimedia.org/wiki/File:Kelly,_Grace_(Rear_Window).jpg
  }

  if ((imgload.width > mainwidth) || (imgload.height > mainheight)) {

    if (((float) imgload.width / (float)imgload.height) > ((float) mainwidth / (float) mainheight))
    { 
      imgload.resize(mainwidth, 0);
    }
    else
    { 
      imgload.resize(0, mainheight);
    }
  } 

  if  (imgload.height < (mainheight - 2) ) { 
    tempy = (int) (( mainheight - imgload.height ) / 2) ;
  }
  if (imgload.width < (mainwidth - 2)) {
    tempx = (int) (( mainwidth - imgload.width ) / 2) ;
  }

  img.copy(imgload, 0, 0, imgload.width, imgload.height, tempx, tempy, imgload.width, imgload.height);
  // For background image!


  /* 
   // Optional gamma correction for background image.  
   img.loadPixels();
   
   float tempFloat;  
   float GammaValue = 1.0;  // Normally in the range 0.25 - 4.0
   
   for (int i = 0; i < img.pixels.length; i++) {
   tempFloat = brightness(img.pixels[i])/255;  
   img.pixels[i] = color(floor(255 * pow(tempFloat,GammaValue))); 
   } 
   img.updatePixels();
   */


  imgblur.copy(img, 0, 0, img.width, img.height, 0, 0, img.width, img.height);
  // This is a duplicate of the background image, that we will apply a blur to,
  // to reduce "high frequency" noise artifacts.

  imgblur.filter(BLUR, 1);  // Low-level blur filter to elminate pixel-to-pixel noise artifacts.
  imgblur.loadPixels();
}
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

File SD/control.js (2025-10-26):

class Control {
    constructor() {        
        this.canvas = document.getElementById("machine");
        this.ctx = this.canvas.getContext("2d");

        this.machine_specs = {};
        this.pen = {};
        this.page = {};
        this.home = {};
        this.config = {};

        this.isDragging = false;
        this.lastX = 0;
        this.lastY = 0;
        this.offsetX = 0;
        this.offsetY = 0;
        this.scale = 1;
        this.pen_down = true; // down
           
        this.init(); 
    }

    cambio_plugin_captura(event){
        const select = document.getElementById("select_capturar")
        // busco el nombre del plugin seleccionado
        var seleccionado = $(select).val();   
      
        // llamo a la funcion que carga las configuraciones de captura
        window[seleccionado](captura.imagen);
    }

    cargar_archivo_gcode(event){
        let selectedFile = event.target.files[0];
     
        if (selectedFile) {        
            const reader = new FileReader();    
            reader.onload = (e) => {
            
                // Crear objeto con información del archivo
                const fileData = {
                    name: selectedFile.name,
                    type: selectedFile.type,
                    size: selectedFile.size,
                    lastModified: selectedFile.lastModified,
                    content: e.target.result, // Contenido en base64 o texto
                    arrayBuffer: null
                };

                if (selectedFile.type.startsWith("text/")) {
                    const arrayBufferReader = new FileReader();
                    arrayBufferReader.onload = (arrayBufferEvent) => {
                 
                        fileData.arrayBuffer = arrayBufferEvent.target.result;

                        let cola = fileData.content.split("\n");

                        // limpio la cola de tareas
                        this.limpiar_cola();

                        //limpio las tareas ejecutadas
                        this.limpiar_ejecutadas();   

                        this.tareas.pausar();                     
                        
                        setTimeout(() => {
                            for (const tarea of cola) {
                                if (tarea.startsWith("C") && tarea.includes(",END")) {
                                    this.encolar_tarea(tarea, this.update_pen_position.bind(this),false);
                                } else {
                                    console.warn(" LA TAREA '" + tarea + "' NO PARECE SER GCODE!!");
                                }
                            }
                         
                            // calculo la distancia inicial del dibujo
                            this.tareas.calcularDistanciaRestante(true);

                            this.draw_machine();

                            // muestro todas las tareas
                            $("#tareas").val(this.tareas.mostrar(100000));

                        }, 100);
                        
                    };
                    arrayBufferReader.readAsArrayBuffer(selectedFile);
                }
            };

            // Leer el archivo según su tipo
            if (selectedFile.type.startsWith("text/")) {
                reader.readAsText(selectedFile);
            }
        }
    }


    dobleClick_canvas(event){
        // Calculate the mouse coordinates relative to the canvas
        const rect = this.canvas.getBoundingClientRect();
        let x = event.clientX - rect.left;
        let y = event.clientY - rect.top;

        // corrijo las coordenadas teniendo en cuenta el zoom y el offset
        let w = this.screenToWorld(x, y);

        if (this.config.mover_gondola) {
            // calculo los datos de la nueva posicion
            let pen_x = Math.round(w.x);
            let pen_y = Math.round(w.y);

            let motorA = this.calc_motorA(pen_x, pen_y);
            let motorB = this.calc_motorB(pen_x, pen_y);

            // envio la terea, cuando termine actualiza los datos de posicion
            this.encolar_tarea('C01,'+motorA+','+motorB+',END',this.update_pen_position.bind(this));
        }else{
            // guardo la nueva posicion
            this.pen.x = Math.round(w.x);
            this.pen.y = Math.round(w.y);

            $("#pen_x").val(this.pen.x);
            $("#pen_y").val(this.pen.y);

            this.pen.motorA = this.calc_motorA(this.pen.x, this.pen.y);
            this.pen.motorB = this.calc_motorB(this.pen.x, this.pen.y);

            $("#pen_motorA").html(this.pen.motorA);
            $("#pen_motorB").html(this.pen.motorB);

            this.guardar_parametros();
        }
    }

    // Eventos para el zoom
    wheel_canvas(event){
        event.preventDefault();
    
        const rect = this.canvas.getBoundingClientRect();
        const mouseX = event.clientX - rect.left;
        const mouseY = event.clientY - rect.top;
        
        const zoomIntensity = 0.1;
        const wheel = event.deltaY < 0 ? 1 : -1;
        const zoom = Math.exp(wheel * zoomIntensity);
        
        // Calcular nuevo scale y offset
        this.offsetX -= (mouseX - this.offsetX) * (zoom - 1);
        this.offsetY -= (mouseY - this.offsetY) * (zoom - 1);
        this.scale *= zoom;        

        this.draw_machine();
    }

    // Pan (arrastrar)
    mousedown_canvas(event){
        this.isDragging = true;
        this.lastX = event.clientX;
        this.lastY = event.clientY;
    }

    mousemove_canvas(event){
        if (this.isDragging) {
            this.offsetX += (event.clientX - this.lastX) / this.scale;
            this.offsetY += (event.clientY - this.lastY) / this.scale;
            this.lastX = event.clientX;
            this.lastY = event.clientY;                  
            this.draw_machine();       
        }
    }

    mouseup_canvas(event){
        this.isDragging = false;
    }

    mouseleave_canvas(event){
        this.isDragging = false;
    }

    comando_gcode_keydown(event){
        if (event.key === "Enter") {
        // Prevent the default form submission behavior if the input is within a form
        event.preventDefault(); 

        let comando = $("#comando_gcode").val().toUpperCase();
        //valido el gcode
            if (gcode_valido(comando)){
                $("#comando_gcode").val('');
                this.encolar_tarea(comando, this.update_pen_position.bind(this));
            }else{
                alert("gcode " + comando + " no valido!");
            }
        }
    }
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

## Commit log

2024-05-28 Add files via upload
    add files
    [BasePlate PCB.stl, Sledge.f3d, Sledge.stl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]
2024-05-28 quito edicion de sd card
2024-06-07 agrego generacion de imagenes con puntos StippleGen2
    [BasePlate Uno.stl, BasePlate.f3d, Hook.stl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]
2024-06-12 agrego edicion de sd
    [BasePlate PCB.stl, BasePlate Uno.stl, BasePlate.f3d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]
2024-06-13 agrego carga de editor de sd
2024-07-05 cambio modo de seleccion de velocidades
2024-07-08 agrego calibrado
    [circuito.fzz]
2024-08-15 update circuito
    [circuito.fzz]
2025-08-22 cambios en editor de SD
2025-08-23 quito limitacion de maximo de caracteres en archivos subidos desde edit
2025-09-05 modifico paso parametros de comandos
2025-09-11 actualizo web control, agrego generador de mapas de fuerza
2025-09-14 agrego cola de tareas
2025-09-18 corrijo cambio de gondola con zoom
2025-09-21 agrego caputura de imagenes
2025-09-28 agrego captura de imagenes
2025-10-01 agrego capturas de imagenes como plugins
2025-10-04 cambios en seleccion de elementos
2025-10-04 limpieza de codigo
2025-10-10 agrego archivos gcode de test
2025-10-10 auto selecciona vertices que entran en la pagina
2025-10-10 cambio select por radio button en selecionar modo
2025-10-11 quito modo de seleccion y agrego optimizado de recorridos
2025-10-11 agrego descarga de colas
2025-10-12 cambio forma de cargar scripts
2025-10-12 implemento rotacion de imagen
2025-10-12 corrijo mostrado de dibujo
2025-10-12 corrijo problemas de rotacion y seleccion
2025-10-12 corrijo calculo de centro de rotacion
2025-10-12 llamo a rotar solo si hay que modifcar el angulo
2025-10-14 agrego controles para canny
2025-10-16 agrego estadisticas de tiempo estimado
2025-10-17 cambio manejo de estadisticas
2025-10-17 mejoro algoritmo de reduccion de vertices
2025-10-17 agrando cantidad de tareas mostradas
2025-10-18 cambio velocidad de estadisticas de cm/seg a mm/seg
2025-10-18 agrego configuracion de tareas mostradas
2025-10-18 agrego opciones de interface
2025-10-18 modifico para que funcione con github pages y cdn
2025-10-19 agrego soporte parcial para archivos svg
2025-10-20 actualizo svg de ejemplo
2025-10-22 mejoro dibujado de colas
2025-10-24 muestra avance de carga en canny
2025-10-25 reacomodo elemetnos de la interface
